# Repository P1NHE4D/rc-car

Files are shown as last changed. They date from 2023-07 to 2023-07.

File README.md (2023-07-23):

# RC Car Project
This repository contains all files for the controller boards I designed for a RC car I am building myself.

## Version 1
The first version of the board uses a AtMega 328 MCU for controlling the motor driver, lights, and steering of the car. It is connected to an external
ESP 8266 chip for enabling wireless communication.

<div align="center">
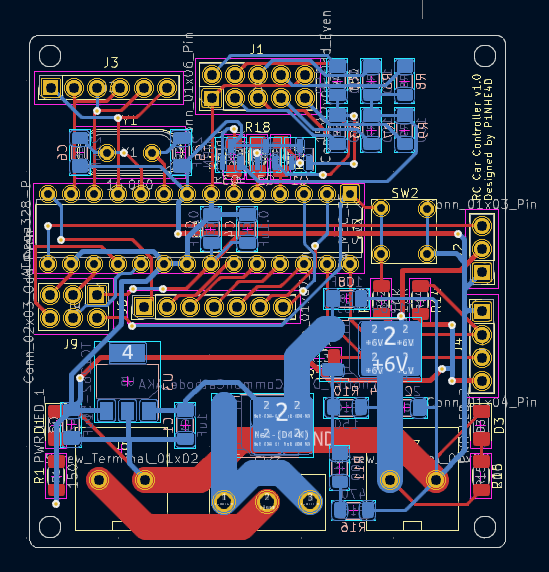
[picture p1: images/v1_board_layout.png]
V1 Board Layout
  
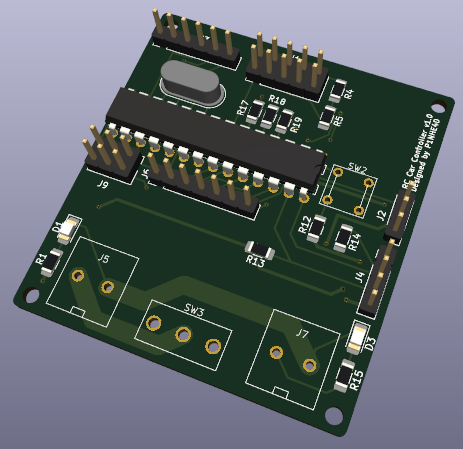
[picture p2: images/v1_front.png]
V1 PCB Front
  
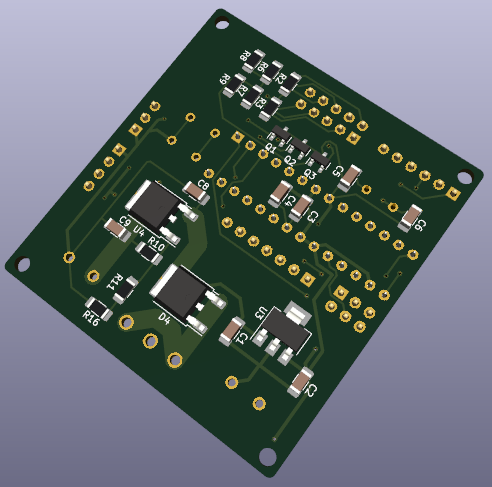
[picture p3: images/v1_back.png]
V1 PCB Back
  
</div>

## Version 2
The second version is currently in development. It replaces the AtMega 328 chip with an on-board ESP32 in order to reduce the overall footprint
of the chip. It also features a USB-C connector to facilitate flashing and debugging the controller without having to rely on additional 
debugging equipment.

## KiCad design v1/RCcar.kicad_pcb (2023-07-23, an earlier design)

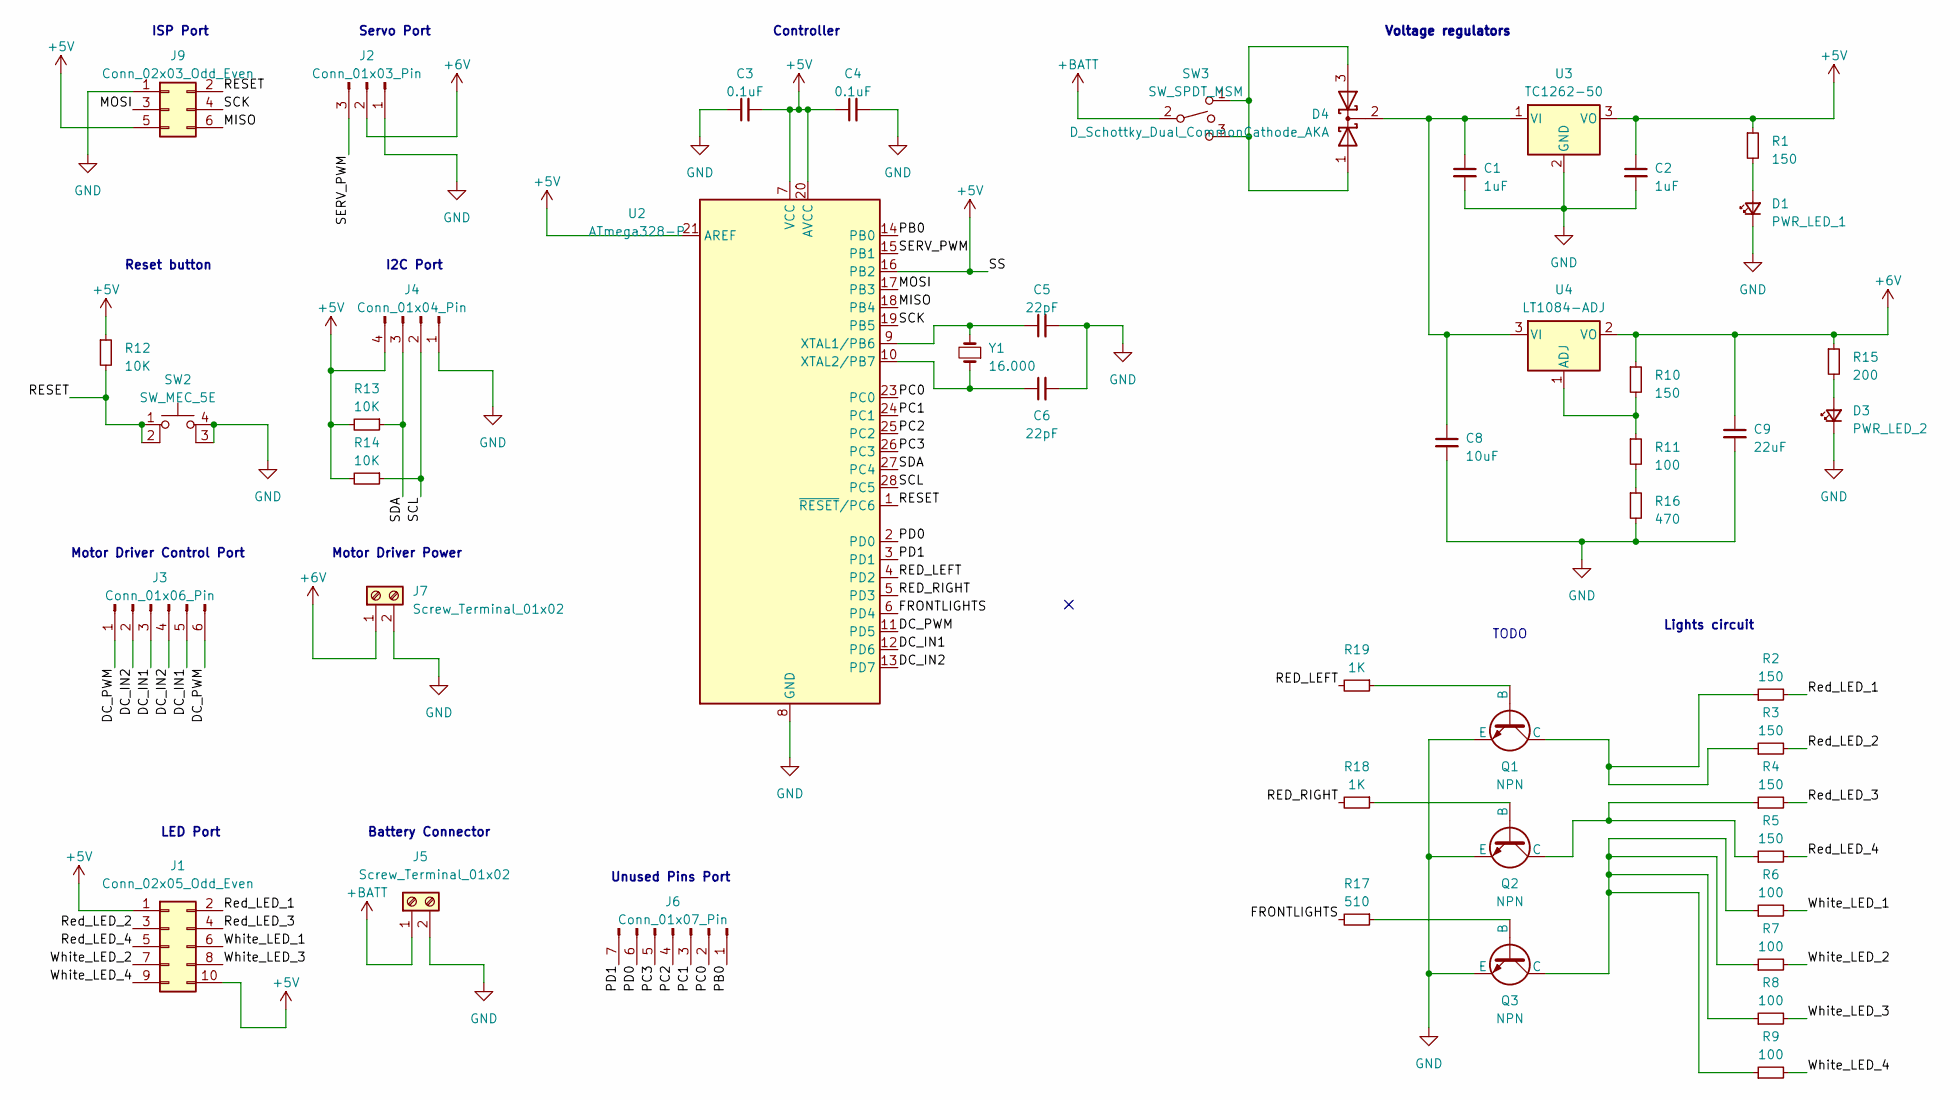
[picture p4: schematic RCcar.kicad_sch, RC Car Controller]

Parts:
C1, C2: 1uF; C_1206_3216Metric_Pad1.33x1.80mm_HandSolder
C3, C4: 0.1uF; C_1206_3216Metric_Pad1.33x1.80mm_HandSolder
C5, C6: 22pF; C_1206_3216Metric_Pad1.33x1.80mm_HandSolder
C8: 10uF; C_1206_3216Metric_Pad1.33x1.80mm_HandSolder
C9: 22uF; C_1206_3216Metric_Pad1.33x1.80mm_HandSolder
D1: PWR_LED_1; LED_1206_3216Metric_Pad1.42x1.75mm_HandSolder
D3: PWR_LED_2; LED_1206_3216Metric_Pad1.42x1.75mm_HandSolder
D4: D_Schottky_Dual_CommonCathode_AKA; TO-252-2
J1: Conn_02x05_Odd_Even; PinHeader_2x05_P2.54mm_Vertical
J2: Conn_01x03_Pin; PinHeader_1x03_P2.54mm_Vertical
J3: Conn_01x06_Pin; PinHeader_1x06_P2.54mm_Vertical
J4: Conn_01x04_Pin; PinHeader_1x04_P2.54mm_Vertical
J5, J7: Screw_Terminal_01x02; CTB0700-2
J6: Conn_01x07_Pin; PinHeader_1x07_P2.54mm_Vertical
J9: Conn_02x03_Odd_Even; PinHeader_2x03_P2.54mm_Vertical
Q1, Q2, Q3: NPN; SOT-23
R1, R2, R3, R4, R5, R10: 150; R_1206_3216Metric_Pad1.30x1.75mm_HandSolder
R6, R7, R8, R9, R11: 100; R_1206_3216Metric_Pad1.30x1.75mm_HandSolder
R12, R13, R14: 10K; R_1206_3216Metric_Pad1.30x1.75mm_HandSolder
R15: 200; R_1206_3216Metric_Pad1.30x1.75mm_HandSolder
R16: 470; R_1206_3216Metric_Pad1.30x1.75mm_HandSolder
R17: 510; R_1206_3216Metric_Pad1.30x1.75mm_HandSolder
R18, R19: 1K; R_1206_3216Metric_Pad1.30x1.75mm_HandSolder
SW2: SW_MEC_5E; ElegooButton
SW3: SW_SPDT_MSM; 1101M2S3CQE2
U2: ATmega328-P; DIP-28_W7.62mm
U3: TC1262-50; SOT-223
U4: LT1084-ADJ; TO-252-2
Y1: 16.000; Crystal_HC49-4H_Vertical

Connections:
+5V: C2.1, C3.2, C4.1, J1.1, J1.10, J4.4, J9.5, R1.1, R12.1, R13.2, R14.2, U2.7 (VCC), U2.16 (PB2), U2.20 (AVCC), U2.21 (AREF), U3.3 (VO)
+6V: C9.1, J2.2, J7.1, R10.1, R15.1, U4.2 (VO)
+BATT: J5.1, SW3.2
/DC_IN1: J3.3, J3.5, U2.12 (PD6)
/DC_IN2: J3.2, J3.4, U2.13 (PD7)
/DC_PWM: J3.1, J3.6, U2.11 (PD5)
/FRONTLIGHTS: R17.2, U2.6 (PD4)
/MISO: J9.6, U2.18 (PB4)
/MOSI: J9.3, U2.17 (PB3)
/PB0: J6.1, U2.14 (PB0)
/PC0: J6.2, U2.23 (PC0)
/PC1: J6.3, U2.24 (PC1)
/PC2: J6.4, U2.25 (PC2)
/PC3: J6.5, U2.26 (PC3)
/PD0: J6.6, U2.2 (PD0)
/PD1: J6.7, U2.3 (PD1)
/RED_LEFT: R19.2, U2.4 (PD2)
/RED_RIGHT: R18.2, U2.5 (PD3)
/RESET: J9.2, R12.2, SW2.1, SW2.2, U2.1 (~RESET/PC6)
/Red_LED_1: J1.2, R2.2
/Red_LED_2: J1.3, R3.2
/Red_LED_3: J1.4, R4.2
/Red_LED_4: J1.5, R5.2
/SCK: J9.4, U2.19 (PB5)
/SCL: J4.2, R14.1, U2.28 (PC5)
/SDA: J4.3, R13.1, U2.27 (PC4)
/SERV_PWM: J2.3, U2.15 (PB1)
/White_LED_1: J1.6, R6.2
/White_LED_2: J1.7, R7.2
/White_LED_3: J1.8, R8.2
/White_LED_4: J1.9, R9.2
GND: C1.2, C2.2, C3.1, C4.2, C5.2, C6.2, C8.2, C9.2, D1.1 (K), D3.1 (K), J2.1, J4.1, J5.2, J7.2, J9.1, Q1.3 (E), Q2.3 (E), Q3.3 (E), R16.2, SW2.3 (K), SW2.4 (A), U2.8 (GND), U2.22 (GND), U3.2 (GND)
unnamed: D1.2 (A), R1.2
unnamed: D3.2 (A), R15.2
unnamed: D4.1 (A), D4.3 (A), SW3.1, SW3.3
unnamed: C1.1, C8.1, D4.2 (K), U3.1 (VI), U4.3 (VI)
unnamed: Q1.2 (B), R19.1
unnamed: Q1.1 (C), R2.1, R3.1
unnamed: Q2.2 (B), R18.1
unnamed: Q2.1 (C), R4.1, R5.1
unnamed: Q3.2 (B), R17.1
unnamed: Q3.1 (C), R6.1, R7.1, R8.1, R9.1
unnamed: R11.2, R16.1
unnamed: C5.1, U2.9 (XTAL1/PB6), Y1.2
unnamed: C6.1, U2.10 (XTAL2/PB7), Y1.1
unnamed: R10.2, R11.1, U4.1 (ADJ)

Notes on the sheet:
Servo Port
LED Port
Voltage regulators
Reset button
Lights circuit
TODO
Battery Connector
Motor Driver Power
Controller
ISP Port
Motor Driver Control Port
I2C Port
Unused Pins Port

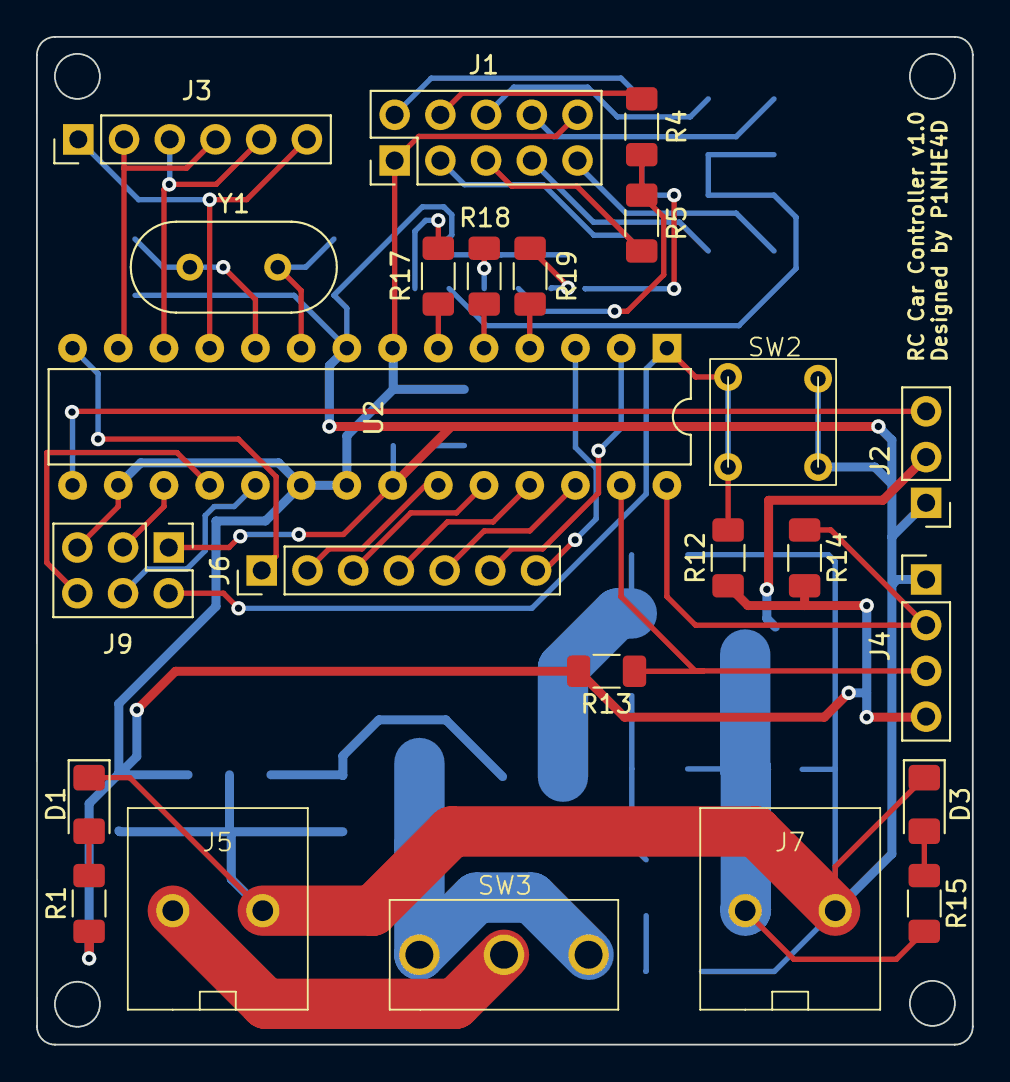
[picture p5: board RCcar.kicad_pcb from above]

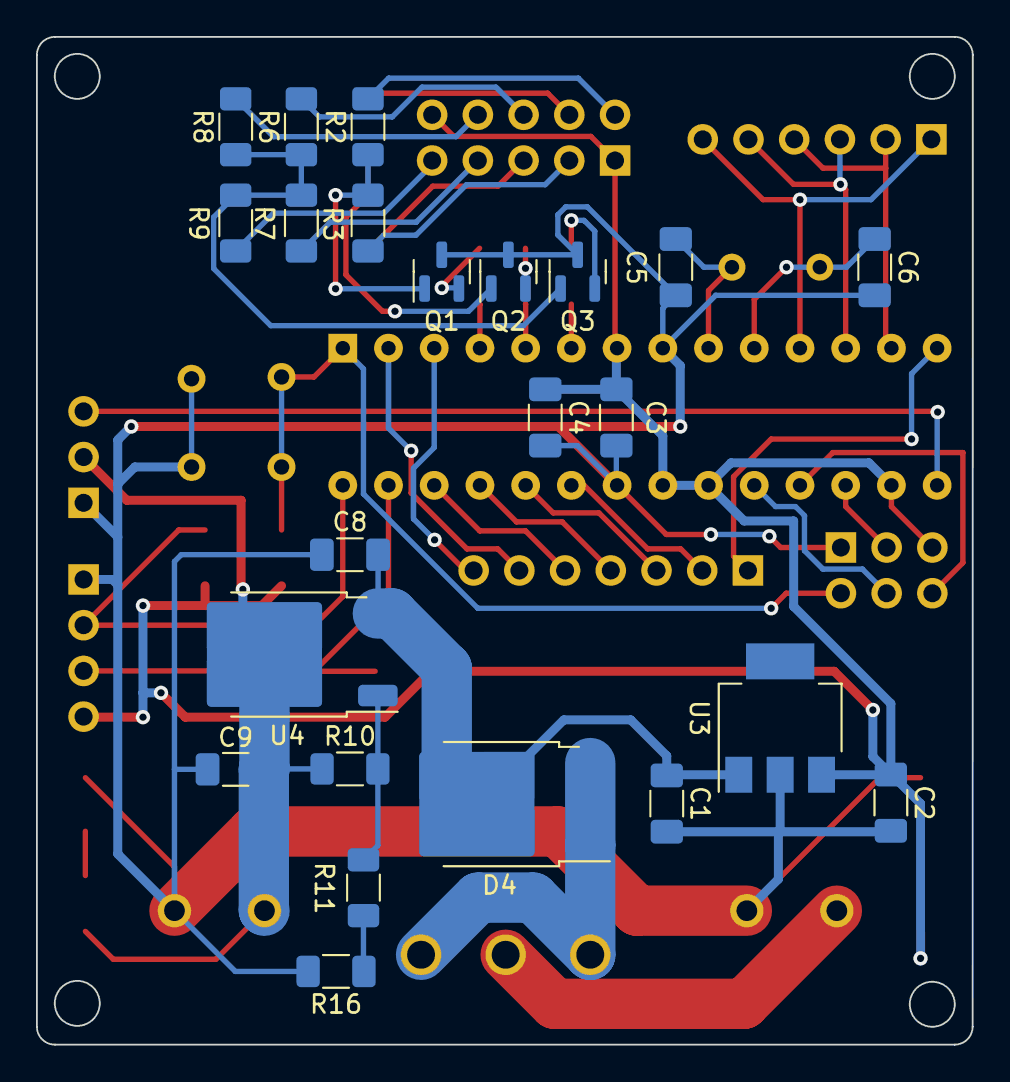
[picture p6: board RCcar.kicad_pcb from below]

Board: 2 copper layers, 52.0 x 56.0 mm, 47 parts (23 on the bottom side), 46 nets.

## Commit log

2023-07-23 add v1 files
    [RCcar-B_Cu.gbr, RCcar-B_Mask.gbr, RCcar-B_Paste.gbr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]
2023-07-23 add subfolder
    [RCcar-B_Cu.gbr, RCcar-B_Mask.gbr, RCcar-B_Paste.gbr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]
2023-07-23 add v2 files
    [rc-car-v2.kicad_pcb, rc-car-v2.kicad_sch]
